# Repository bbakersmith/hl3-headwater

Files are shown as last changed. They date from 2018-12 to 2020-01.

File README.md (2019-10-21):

# HL3 Headwater

A digital clock source built around an ATMega328P for driving eurorack audio and
video synthesizer modules. Features include syncronization with external CV and
MIDI clock sources, three separate CV output channels, MIDI clock output, two
discreet multipliers, saving and loading of custom presets, LCD and rotary
encoder based UI, and an SPI API for serial control.

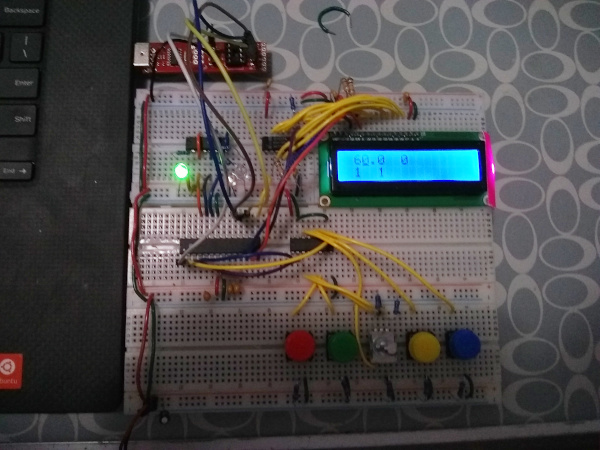
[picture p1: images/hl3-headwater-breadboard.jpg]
HL3 Headwater breadboard


# License

Copyright Ben Baker-Smith 2019.

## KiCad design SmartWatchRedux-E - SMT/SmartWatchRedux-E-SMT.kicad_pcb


Board: 2 copper layers, 24.7 x 69.9 mm, 6 parts (0 on the bottom side), 33 nets.

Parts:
BAT1: CR2032; BatteryHolder_Keystone_1060_1x2032
C1: 0.1uF; C_1206_3216Metric
CN1: 27C256Socket; DIP-28_W15.24mm
U1: ROM; DIP-28_W15.24mm_Socket
U2: DS1315; DIP-16_W7.62mm
Y1: 32.768 KHz; Crystal_SMD_3215-2Pin_3.2x1.5mm

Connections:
/XTAL1: U2.1, Y1.1
/XTAL2: U2.2, Y1.2
GND: BAT1.2, C1.2, CN1.14, U1.14, U2.5, U2.8, U2.14
unnamed: BAT1.1, U2.4
unnamed: CN1.1, U1.1, U2.13
unnamed: CN1.2, U1.2
unnamed: CN1.3, U1.3
unnamed: CN1.4, U1.4
unnamed: CN1.5, U1.5
unnamed: CN1.6, U1.6
unnamed: CN1.7, U1.7
unnamed: CN1.8, U1.8, U2.3
unnamed: CN1.9, U1.9
unnamed: CN1.10, U1.10, U2.6
unnamed: CN1.11, U1.11, U2.7
unnamed: CN1.12, U1.12
unnamed: CN1.13, U1.13
unnamed: CN1.15, U1.15
unnamed: CN1.16, U1.16
unnamed: CN1.17, U1.17
unnamed: CN1.18, U1.18
unnamed: CN1.19, U1.19
unnamed: CN1.20, U2.11
unnamed: CN1.21, U1.21
unnamed: CN1.22, U1.22, U2.12
unnamed: CN1.23, U1.23
unnamed: CN1.24, U1.24
unnamed: CN1.25, U1.25
unnamed: CN1.26, U1.26
unnamed: CN1.27, U1.27
unnamed: U1.20, U2.10
unnamed: U2.9, U2.15
VCC: C1.1, CN1.28, U1.28, U2.16

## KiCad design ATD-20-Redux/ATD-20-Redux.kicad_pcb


Board: 2 copper layers, 24.3 x 64.1 mm, 5 parts (0 on the bottom side), 9 nets.

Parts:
BAT1: CR2032; BatteryHolder_Keystone_1060_1x2032
C1: 0.1uF; C_Disc_D4.3mm_W1.9mm_P5.00mm
J1: RTC Pins; DIP-28_W15.24mm_Socket
U1: DS1315; DIP-16_W7.62mm
Y1: 32.768 KHz; Crystal_C38-LF_D3.0mm_L8.0mm_Horizontal

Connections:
/D0: J1.11, U1.6, U1.7
/XTAL1: U1.1, Y1.1
/XTAL2: U1.2, Y1.2
/~CS_RTC: J1.20, U1.11
/~IOR: J1.22, U1.12
/~IOW: J1.27, U1.3
GND: BAT1.2, C1.2, J1.14, U1.5, U1.8, U1.9, U1.14
unnamed: BAT1.1, U1.4
VCC: C1.1, J1.28, U1.13, U1.16

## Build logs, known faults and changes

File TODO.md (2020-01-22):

COMPLETE
========

X headwater_lcd moved into headwater_ui
X get multiplier_b working
X headwater_state moved out of headwater_api (only reference as a pointer)
X holding down rotary encoder button should execute changes immediately
X make atmega_io ns

NO parameterize / disable spi api in preprocessor
  - this isn't worth the savings right now. about 1k bytes program, 17 bytes data

NO remove button hold count
  - no real gains for removing it, could be useful

X move all the excess in atmega_headwater into appropriate modules

X move ui inputs into headwater_ui
  X struct of all inputs

NO all blocks in atmega_headwater (main, interrupts) should
  contain a single function call to a new central headwater module

  NO move remaining non-atmega specific code into headwater module
  X move remaining atmega specific code into other / new atmega modules

X stop on all mode changes may be a bit heavy...
  NO only stop on ext and midi?
  X does it need to stop at all? could just reset counts

X overflow issue where int playback stops after apx 65.535 seconds :p
  X play will no longer work until switch to ext and switch back

X loading a preset stops playback in internal mode

X bpm should be uint16 rather than int16

X multiplier rounding results in offset outputs from a and b that should be synced
  - ex. bpm = 135, a = 4, b = 8, outputs varying up to 2 samples (ms) apart

X multiplier set to 0 should not output ever (or minimum should be 1)
  - right now it behaves the same as 1, might be a ui / field minimum mismatch

X mode: internal
  X auto loop based on internal bpm
  X bpm UI enabled

X mode: external
  X don't auto loop based on internal bpm
  X after each play, re-calculate
    X bpm (for disiplay)
    X samples for multipliers

X output midi clock (3rd x24 multiplier channel?) based on bpm

X internal mode: only update clock speed (samples) for bpm and / or multipliers after each beat

X midi output
  x continue (0xFB) instead of start (0xFA) on play?
  X midi writer (uart out) shouldn't block, use queue instead
  NO active sensing (0xFE) output every 300ms to keep slave waiting?
     seems like a good idea, but apparently not widely implemented
     and doesn't seem to work with the mpc

TODO HIGH
=========

- pcb design
  - decide on if hl3 will feature midi in
  - schematic
  - ui / front panel layout
  - pcb layout
  - BUGFIXES
    - xtal pads are wrong
    - 0802 LCD connector is upside down
    - stop / play LED not connected to MCU
    - need silk labels on connectors
    - need polarity labels on LEDs and diodes
    - stop / play LED needs smaller value resistor

- mode: tap
  X auto loop based on internal bpm
  - tap should not trigger play, just recalculation of bpm?
    or at least need to nail down how slow down of tap vs bpm should work
    with looping
  - after each play, re-calculate
    - bpm (for display and ongoing playback)
    - samples for multipliers
  - take into account time between last N taps?

- ui range restriction stops display / value,
  but the uncommitted modifier keeps counting, which is bad
  - put min max on all fields?
  - store actual value instead of uncomitted modifier?
    - would have to use another method of detecting change...

- mode: midi
  * might want to scrap midi mode and only provide midi output
    due to complexity of logic
  * might want to limit multipliers to max of 24 in midi mode to guarantee
    one initial clock after start by which to measure base BPM and calculate
    multiplier samples per beat
  - input commands
    - stop (0xFC)
    - start (0xFA) and (0xFB) continue synonyms
    - clock (0xF8) for timing
  - play every beat (1/24?) of incoming midi clock
    - reuse state.samples_since_reset_count
    - will need another counter for division by 24
  - calculate bpm from incoming midi clock
  - passthrough to midi output?

TODO LOW
========

- external and midi modes: disable bpm in UI

- rename LCD_MODE states, reading / writing is confusing

- reset needs overhaul, play & reset are same now

- make lcd module work with various row / column sizes (specifically 8x2)

- should button change be handled in interrupt?
  - seems generally unnecessary
  - button debouncing would be a lot more effective / tunable

- accept midi program change messages to change current preset?

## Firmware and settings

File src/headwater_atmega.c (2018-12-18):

#include "stdint.h"
#include "headwater.h"
#include <avr/interrupt.h>
#include <avr/io.h>


#define F_CPU 16000000UL  // 16 MHz
#include <util/delay.h>


#define INPUT_PORT PORTC
#define INPUT_DDR DDRC


#define OUTPUT_PORT PORTD
#define OUTPUT_DDR DDRD


#define MULTIPLEX_PORT PORTB
#define MULTIPLEX_DDR DDRB


static uint8_t MULTIPLEX_S1 = PORTB0;
static uint8_t MULTIPLEX_S2 = PORTB1;


static uint8_t TBPM_ENCODER_A = PORTC0;
static uint8_t TBPM_ENCODER_B = PORTC1;


static uint8_t OUTPUT_PIN = PORTD5;
static uint8_t MULTIPLIED_PIN = PORTD6;
static uint8_t DEBUG_PIN = PORTD7;


static const uint8_t MULTIPLEX_SELECT_MODA = 0;
static const uint8_t MULTIPLEX_SELECT_MODB = 1;
static const uint8_t MULTIPLEX_SELECT_PRESET = 2;
static const uint8_t MULTIPLEX_SELECT_BPM = 3;


// should be volatile?
ClockState clock_state;


void atmega_multiplexer_select(uint8_t channel) {
  if(channel == 0) {
      MULTIPLEX_PORT &= ~(1 << MULTIPLEX_S1);
      MULTIPLEX_PORT &= ~(1 << MULTIPLEX_S2);
  } else if(channel == 1) {
      MULTIPLEX_PORT &= ~(1 << MULTIPLEX_S1);
      MULTIPLEX_PORT |= (1 << MULTIPLEX_S2);
  } else if(channel == 2) {
      MULTIPLEX_PORT |= (1 << MULTIPLEX_S1);
      MULTIPLEX_PORT &= ~(1 << MULTIPLEX_S2);
  } else if(channel == 3) {
      MULTIPLEX_PORT |= (1 << MULTIPLEX_S1);
      MULTIPLEX_PORT |= (1 << MULTIPLEX_S2);
  }
}


void atmega_update_output(uint8_t enabled) {
  if(enabled == 0) {
    OUTPUT_PORT &= ~(1 << OUTPUT_PIN);
  } else {
    OUTPUT_PORT |= (1 << OUTPUT_PIN);
  }
}


void atmega_update_multiplied(uint8_t enabled) {
  if(enabled == 0) {
    OUTPUT_PORT &= ~(1 << MULTIPLIED_PIN);
  } else {
    OUTPUT_PORT |= (1 << MULTIPLIED_PIN);
  }
}


// atmega SPI functionality


// mosi output
// miso input (implied by master mode)
// sck output
// ss output


#define MOSI PORTB3
#define SCK PORTB5
#define SS PORTB2
#define ENC1A PORTD0
#define ENC1B PORTD1
#define ENC1SW PORTD2


void spi_master_init(void) {
  // set CS high
  PORTB |= (1 << SS);
  /* Set MOSI, SCK, and SS (PORTB2) output, all others input */
  DDRB = (1 << MOSI) | (1 << SCK) | (1 << SS);
  /* Enable SPI, Master, set clock rate fck/16 */
  SPCR = (1 << SPE) | (1 << MSTR) | (0 << SPR1) | (1 << SPR0);
}


uint8_t spi_master_transmit(uint8_t data) {
  /* Start transmission */
  SPDR = data;
  /* Wait for transmission complete */
  while(!(SPSR & (1 << SPIF)));
  /* Return data from MISO? */
  return(SPDR);
}


static uint8_t MAX7221_DIGIT_0 = 1;
static uint8_t MAX7221_DIGIT_1 = 2;
static uint8_t MAX7221_DIGIT_2 = 3;
static uint8_t MAX7221_DIGIT_3 = 4;
static uint8_t MAX7221_DIGIT_4 = 5;
static uint8_t MAX7221_DIGIT_5 = 6;
static uint8_t MAX7221_DIGIT_6 = 7;
static uint8_t MAX7221_DIGIT_7 = 8;
static uint8_t MAX7221_DECODE_MODE = 9;
static uint8_t MAX7221_INTENSITY = 10;
static uint8_t MAX7221_SCAN_LIMIT = 11;
static uint8_t MAX7221_SHUTDOWN = 12;
static uint8_t MAX7221_DISPLAY_TEST = 16;

static uint8_t MAX7221_DIGIT_DECIMAL_BIT = 7;
static uint8_t MAX7221_DIGIT_VALUE_DASH = 10;
static uint8_t MAX7221_DIGIT_VALUE_OFF = 15;

static uint8_t MAX7221_INTENSITY_MIN = 0;
static uint8_t MAX7221_INTENSITY_MAX = 16;

static uint8_t MAX7221_SHUTDOWN_DISABLE = 1;
static uint8_t MAX7221_SHUTDOWN_ENABLE = 0;

static uint8_t MAX7221_DISPLAY_TEST_DISABLE = 0;
static uint8_t MAX7221_DISPLAY_TEST_ENABLE = 1;


void max7221_write(uint8_t address, uint8_t data) {
  // set CS low
  PORTB &= ~(1 << SS);

  spi_master_transmit(address);
  spi_master_transmit(data);

  // set CS high
  PORTB |= (1 << SS);
}


void max7221_start(void) {
  max7221_write(MAX7221_SHUTDOWN, 1);
}


void max7221_stop(void) {
  max7221_write(MAX7221_SHUTDOWN, 0);
}


void max7221_intensity(uint8_t level) {
  // 0 - 16
  max7221_write(MAX7221_INTENSITY, level);
}


void max7221_code_b_decode(uint8_t digits) {
  max7221_write(MAX7221_DECODE_MODE, digits);
}


void max7221_limit_digits(uint8_t num_digits) {
  // 1 - 8
  max7221_write(MAX7221_SCAN_LIMIT, num_digits - 1);
}


void max7221_enable_display_test(void) {
  max7221_write(MAX7221_DISPLAY_TEST, 1);
}


void max7221_disable_display_test(void) {
  max7221_write(MAX7221_DISPLAY_TEST, 0);
}


// FIXME
uint8_t max7221_digit_with_decimal(uint8_t digit) {
  digit |= (1 << MAX7221_DIGIT_DECIMAL_BIT);
  return digit;
}


void max7221_write_blank(uint8_t digit) {
  max7221_write(digit, MAX7221_DIGIT_VALUE_OFF);
}


void max7221_write_dash(uint8_t digit) {
  max7221_write(digit, MAX7221_DIGIT_VALUE_DASH);
}


void max7221_write_4digit_number(uint16_t number) {
  uint8_t index = 4;
  while(0 < index) {
    if(0 < number) {
      uint8_t digit = number % 10;
      if(index == 3) {
        digit = max7221_digit_with_decimal(digit);
      }
      max7221_write(index, digit);
      number /= 10;
    } else {
      max7221_write_blank(index);
    }
    index -= 1;
  }
}

void max7221_initialize(uint8_t intensity, uint8_t num_digits) {
  max7221_code_b_decode(0xFF);
  max7221_intensity(intensity);
  max7221_limit_digits(num_digits);
  max7221_start();
}

uint8_t debug_toggle_state = 0;
void debug_toggle(void) {
  if(debug_toggle_state) {
    OUTPUT_PORT &= ~(1 << DEBUG_PIN);
    debug_toggle_state = 0;
  } else {
    OUTPUT_PORT |= (1 << DEBUG_PIN);
    debug_toggle_state = 1;
  }
}

void main(void) {
  // enable pins
  OUTPUT_DDR |= (1 << OUTPUT_PIN) | (1 << MULTIPLIED_PIN) | (1 << DEBUG_PIN);
  MULTIPLEX_DDR |= (1 << MULTIPLEX_S1) | (1 << MULTIPLEX_S2);

  /* Enable rotary encoder inputs */
  PORTD |= (1 << ENC1A) | (1 << ENC1B) | (1 << ENC1SW);

  // timer clear timer on compare (ctc) mode
  TCCR1A |= (0 << WGM11) | (0 << WGM10);
  TCCR1B |= (0 << WGM13) | (1 << WGM12);

  // timer prescale
  TCCR1B |= (0 << CS12) | (1 << CS11) | (0 << CS10);

  // timer reset value
  OCR1A = 2000;

  // enable interrupts
  TIMSK1 |= (1 << OCIE1A);
  PCMSK1 |= (1 << PCINT8) | (1 << PCINT9);
  sei();

  _delay_ms(1000);
  spi_master_init();
  max7221_initialize(0, 4);

  clock_state = create_clock_state();
  update_clock_config(&clock_state, 1200, 2);
  start_clock(&clock_state);

  uint8_t enc_bpm_enabled = 0;
  uint8_t enc_moda_enabled = 0;

  /*
  uint32_t x = 200000;
  uint16_t y = 28;
  total = x / y;
  uint16_t number = 3001;
  uint16_t number = 1089;
  */

  while(1) {
    /* handle rotary encoder input */
    uint8_t changed = 0;
    uint16_t new_tbpm = clock_state.tbpm;
    uint8_t new_multiplier = clock_state.multiplier;

    /* debug_toggle(); */

    // TODO set BPM encoder multiplexer address
    // seems to work externally but won't read or respond to inputs
    // when set to anything but 0
    atmega_multiplexer_select(MULTIPLEX_SELECT_BPM);

    // this sucks, hopefully a breadboard problem
    _delay_us(500);

    if(!(PIND & (1 << ENC1A))) {
      if(enc_bpm_enabled == 0) {
        new_tbpm = modify_tbpm(
          clock_state.tbpm,
          (PIND & (1 << ENC1B)),
          (PIND & (1 << ENC1SW))
        );
        enc_bpm_enabled = 1;
        changed = 1;
      }
    } else {
      enc_bpm_enabled = 0;
    }

    atmega_multiplexer_select(MULTIPLEX_SELECT_MODA);

    // this sucks, hopefully a breadboard problem
    _delay_us(500);

    if(!(PIND & (1 << ENC1A))) {
      if(enc_moda_enabled == 0) {
        new_multiplier = modify_multiplier(
          clock_state.multiplier,
          (PIND & (1 << ENC1B))
        );
        enc_moda_enabled = 1;
        changed = 1;
      }
    } else {
      enc_moda_enabled = 0;
    }

    if(changed == 1) {
      update_clock_config(&clock_state, new_tbpm, new_multiplier);
    }

    max7221_write_4digit_number(clock_state.tbpm);

    /* debug_toggle(); */

    /* total += 1; */
    /* max7221_write_4digit_number(total); */

    /* _delay_ms(1000); */
    /* max7221_intensity(0); */
    /* _delay_ms(1000); */
    /* max7221_intensity(5); */
  }
}


ISR(TIMER1_COMPA_vect) {
  // debug_toggle();

  // debug pin enable
  // OUTPUT_PORT |= (1 << DEBUG_PIN);

  cycle_clock(
    &clock_state,
    &atmega_update_output,
    &atmega_update_multiplied
  );

  // debug pin disable
  // OUTPUT_PORT &= ~(1 << DEBUG_PIN);
}


/*
ISR(PCINT1_vect) {
  // change in input pins

}
*/


// encoder interrupts


// stop / start interrupts

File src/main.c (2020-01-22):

/**
 * @file main.c
 */

#include "stdint.h"
#include <avr/interrupt.h>
#include <avr/io.h>

#include "atmega_eeprom.h"
#include "atmega_io.h"
#include "atmega_lcd.h"
#include "atmega_spi.h"
#include "atmega_uart.h"
#include "bytes.h"
#include "debounce.h"
#include "headwater_api.h"
#include "headwater_state.h"
#include "headwater_ui.h"
#include "lcd.h"
#include "midi.h"
#include "ui.h"

volatile API api;
volatile HeadwaterState state;
volatile HeadwaterUIInputs inputs;
volatile LCD lcd;
volatile MIDI midi;
volatile UIScreen screen;

/**
 * Initialize timers, interrupts, GPIO, and peripherals.
 */
void atmega_headwater_global_register_init(void) {
  // timer clear timer on compare (ctc) mode
  TCCR0A |= (1 << WGM01);
  TCCR1B |= (1 << WGM12);

  // timer prescale
  TCCR0B |= (1 << CS02) | (1 << CS00); // 1/1024
  TCCR1B |= (1 << CS11);               // 1/8

  // timer reset value
  OCR0A = 156;
  OCR1A = 2000;

  // configure interrupts
  TIMSK0 |= (1 << OCIE0A);
  TIMSK1 |= (1 << OCIE1A);

  atmega_io_init();
  atmega_lcd_init();
  atmega_spi_slave_init();
  atmega_uart_init();
}

/**
 * Initialize global state objects.
 */
void atmega_headwater_global_state_init(void) {
  midi = midi_new();
  midi.writer = &atmega_uart_writer;
  midi.writer_is_busy = &atmega_uart_is_busy;

  state = headwater_state_new();
  state.midi = &midi;

  api.payload_preprocessor = &headwater_api_payload_preprocessor;
  api.payload_postprocessor = &headwater_api_payload_postprocessor;
  api.request = api_request_new();
  api.state = &state;

  lcd = lcd_new();
  screen = headwater_ui_main_screen(&state, &lcd);
  lcd.selected_position = ui_selected_position(&screen);

  // load preset 0
  headwater_ui_load_preset(&screen, &state, &atmega_eeprom_read);

  inputs = headwater_ui_inputs_new();
}

/**
 * The program entrypoint, including initialization and the main loop.
 */
int main(void) {
  atmega_headwater_global_register_init();
  atmega_headwater_global_state_init();

  sei(); // enable interrupts

  while(1) {
    if(headwater_state_has_change_now(state.change_flags)) {
      headwater_state_handle_change_now(&state);
      atmega_io_stop_play_output(state.output_enabled);
    } else if(lcd.mode == LCD_MODE_WRITE && ui_is_display_changed(&screen)) {
      ui_update_changed_display(&screen);

      // TODO only send if changed?
      if(ui_selected_modifier(&screen) == 0) {
        atmega_lcd_send_cmd(0x0E); // cursor only
      } else {
        atmega_lcd_send_cmd(0x0F); // cursor blinking
      }

      lcd.mode = LCD_MODE_READ;
    } else {
      headwater_ui_handle_inputs(
        &inputs,
        atmega_io_sample_inputs(8),
        &screen,
        &state,
        &atmega_eeprom_read,
        &atmega_eeprom_write
      );
    }
  }
}

/**
 * Interrupt for refreshing the LCD display. Changes speed depending on LCD
 * mode.
 */
ISR(TIMER0_COMPA_vect) {
  lcd_handle_interrupt(&lcd, &atmega_lcd_send);

  // Reduce interrupt rate when not reading
  if(lcd.mode == LCD_MODE_READ) {
    OCR0A = 1;
  } else {
    OCR0A = 156;
  }
}

/**
 * Interrupt for updating HeadwaterState counts and outputs. This is the
 * heart of the Headwater system.
 */
ISR(TIMER1_COMPA_vect) {
  headwater_state_cycle(&state);

  // TODO FIXME update display after external and tap inputs
  // ...this may not be the right place
  if(
    state.mode == HEADWATER_STATE_MODE_EXTERNAL
    && state.bpm_channel.output != 0
  ) {
    // TODO fix magic number field index
    screen.change_flags |= (1 << 1);
  }

  atmega_io_bpm_output(state.bpm_channel.output);
  atmega_io_multiplier_a_output(state.multiplier_a_channel.output);
  atmega_io_multiplier_b_output(state.multiplier_b_channel.output);

  if(state.midi_channel.output)
    midi.writer(MIDI_CLOCK);
}

/**
 * Interrupt for reading and reacting to inbound SPI commands.
 */
ISR(SPI_STC_vect) {
  SPDR = api_handle_interrupt(&api, SPDR);
}

/**
 * Interrupt for reading inbound MIDI data.
 */
ISR(USART_RX_vect) {
  // TODO midi_read
  // - stop, start, continue
  // - clock (fire play every 24th)
}

/**
 * Interrupt for writing outbound MIDI data.
 */
ISR(USART_TX_vect) {
  midi_write_queue(&midi);
}

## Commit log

2018-12-05 Rotary count up and down and switch to reset
    [headwater_atmega.c]
2018-12-05 Speed up SPI to 1mhz
2018-12-05 Change incrementation amount with encoder switch
2018-12-18 SPI slave working with bus pirate
2018-12-22 Outputs pull down for inverting hex buffer
    [headwater.c]
2019-01-06 API interrupt handler
2019-02-16 Headwater LCD first screen framed out
2019-03-12 Multiplier B and character 0 blanking bugfix
    [headwater_ui.c]
2019-03-13 Modify with restrictions and button hold counts
2019-03-18 Fix tests for lcd_handle_interrupt, still failing
    [atmega_headwater.c]
2019-03-18 Fix LCD update always firing, only fire on change
    [atmega_headwater.c]
2019-03-23 don't load presets if preset id doesn't match
    [headwater_ui.c]
2019-03-23 don't commit preset change if loading fails
    [atmega_headwater.c, headwater_ui.c]
2019-03-23 commit change immediately if encoder sw pressed
2019-03-24 move libs to lib, remove old, fix tests
    [headwater.c, headwater_atmega.c, headwater_attiny.c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]
2019-03-26 samples_per_second must be 32 bit
2019-03-26 ext working, handful of known bugs
    [headwater_ui.c]
2019-04-03 fix bug: playback stopping at samples_since_reset_count overflow
2019-04-10 even distribution algorithm prototyped in sort.py
2019-05-17 Resolve outstanding TODO comments
    [atmega_uart.c, main.c]
2019-05-17 only update channel samples per beat after a beat
2019-05-29 schematic io
    [hl3-headwater.sch]
2019-06-12 decoupling caps, change schematic symbol for jacks
    [hl3-headwater.sch]
2019-07-07 MIDI schematic
    [hl3-headwater.sch]
2019-07-10 Schematic updates
    [hl3-headwater.sch]
2020-01-22 stop / play LED output
2020-02-24 Reverse rotary encoder direction
    [headwater_ui.c]
